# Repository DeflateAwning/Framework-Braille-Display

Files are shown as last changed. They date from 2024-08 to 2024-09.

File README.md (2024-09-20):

# Framework-Braille-Display
A braille display for the Framework 13 laptop's touchpad, hopefully

## Project Status

⚠️ This project is still a work in progress. It is not usable, yet. ⚠️

If you are interested in helping design, test, or advise on this project, please reach out!

I'm not sure how long this project will take. The goal is to have a proof of concept by 2025-06-01.

## What is this?

This is a project to create a refreshable braille display, which is installable in the location of the Framework 13 laptop's touchpad.

A braille display is a device that allows blind and visually impaired people to read text on a computer screen by converting it to braille.

Manufacturing techniques, cost, etc. TBD.

## Why?

I am not blind. I am, however, disappointed in the lack of laptop-compatible braille displays, and the lack of affordable braille displays in general. I believe that an addition to the open source Framework laptop is a great way to make computers more accessible to visually impaired people from all countries.

### Braille Standards

* ISO 17049:2013 (Accessible design — Application of braille on signage, equipment and appliances)

| Parameter | Min (mm) | Max (mm) | Nominal for Embossing (mm) |
|---|---|---|---|
| Dot Base Diameter | 1.5 | 1.6 | 1.44 |
| Dot height | 0.6 | 0.9 | 0.48 |
| Dist. between two dots in the same cell | 2.3 | 2.5 | 2.34 |
| Dist. between corresponding dots in cells (char-to-char) | 6.1 | 7.6 | 6.20 |
| Dist. between corresponding dots in cells (row-to-row) | 10.0 | 10.2 | 10.00 |

### Framework Laptop
* CAD and electrical specs for the Framework 13 laptop: https://github.com/FrameworkComputer/Framework-Laptop-13

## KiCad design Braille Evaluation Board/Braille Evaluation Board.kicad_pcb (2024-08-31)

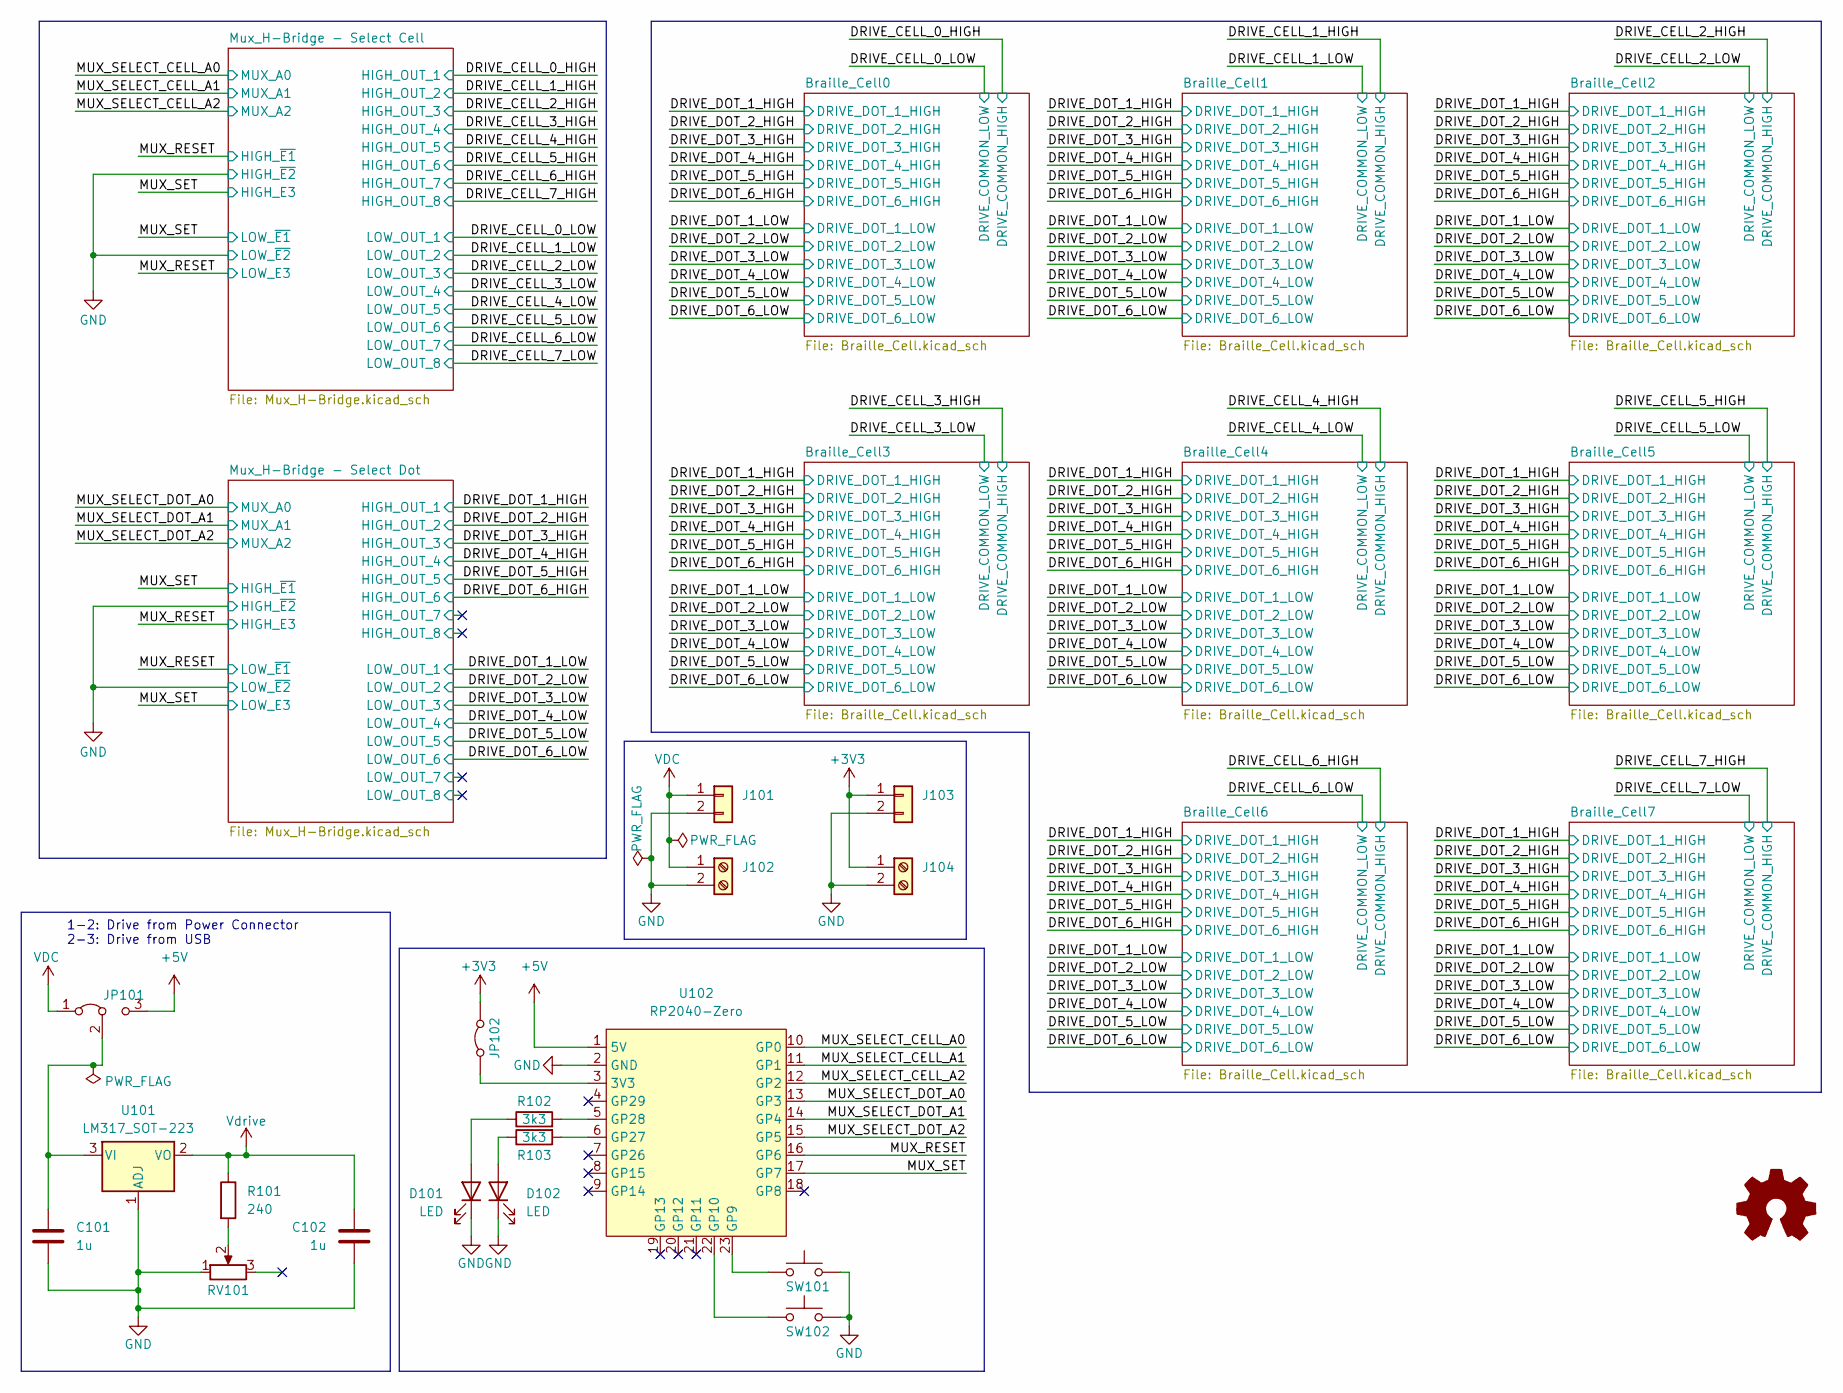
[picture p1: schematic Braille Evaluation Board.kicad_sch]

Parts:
C101, C102: 1u; C_1206_3216Metric_Pad1.33x1.80mm_HandSolder
D101, D102: LED; LED_1206_3216Metric_Pad1.42x1.75mm_HandSolder
J101, J103: Conn_01x02; PinHeader_1x02_P2.54mm_Vertical
J102, J104: Screw_Terminal_01x02; TerminalBlock_bornier-2_P5.08mm
JP101: Jumper_3_Bridged12; PinHeader_1x03_P2.54mm_Vertical
JP102: Jumper_2_Open; PinHeader_1x02_P2.54mm_Vertical
R101: 240; R_1206_3216Metric_Pad1.30x1.75mm_HandSolder
R102, R103: 3k3; R_1206_3216Metric_Pad1.30x1.75mm_HandSolder
RV101: R_Potentiometer; Potentiometer_Vishay_T73YP_Vertical
SW101, SW102: SW_Push; SW_PUSH_6mm_H5mm
U101: LM317_SOT-223; SOT-223-3_TabPin2
U102: RP2040-Zero; RP2040 Zero

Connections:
+3V3: J103.1, J104.1, JP102.2 (B); also elsewhere on the board
+5V: JP101.3 (B), U102.1 (5V)
/MUX_RESET: U102.16 (GP6); also elsewhere on the board
/MUX_SELECT_CELL_A0: U102.10 (GP0); also elsewhere on the board
/MUX_SELECT_CELL_A1: U102.11 (GP1); also elsewhere on the board
/MUX_SELECT_CELL_A2: U102.12 (GP2); also elsewhere on the board
/MUX_SELECT_DOT_A0: U102.13 (GP3); also elsewhere on the board
/MUX_SELECT_DOT_A1: U102.14 (GP4); also elsewhere on the board
/MUX_SELECT_DOT_A2: U102.15 (GP5); also elsewhere on the board
/MUX_SET: U102.17 (GP7); also elsewhere on the board
GND: C101.2, C102.2, D101.1 (K), D102.1 (K), J101.2, J102.2, J103.2, J104.2, RV101.1, SW101.2, SW102.2, U101.1 (ADJ), U102.2 (GND); also elsewhere on the board
unnamed: D101.2 (A), R102.1
unnamed: D102.2 (A), R103.1
unnamed: C101.1, JP101.2 (C), U101.3 (VI)
unnamed: JP102.1 (A), U102.3 (3V3)
unnamed: R101.2, RV101.2
unnamed: SW101.1, U102.23 (GP9)
unnamed: SW102.1, U102.22 (GP10)
unnamed: R103.2, U102.6 (GP27)
unnamed: R102.2, U102.5 (GP28)
VDC: J101.1, J102.1, JP101.1 (A)
Vdrive: C102.1, R101.1, U101.2 (VO); also elsewhere on the board

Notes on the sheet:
1-2: Drive from Power Connector 2-3: Drive from USB

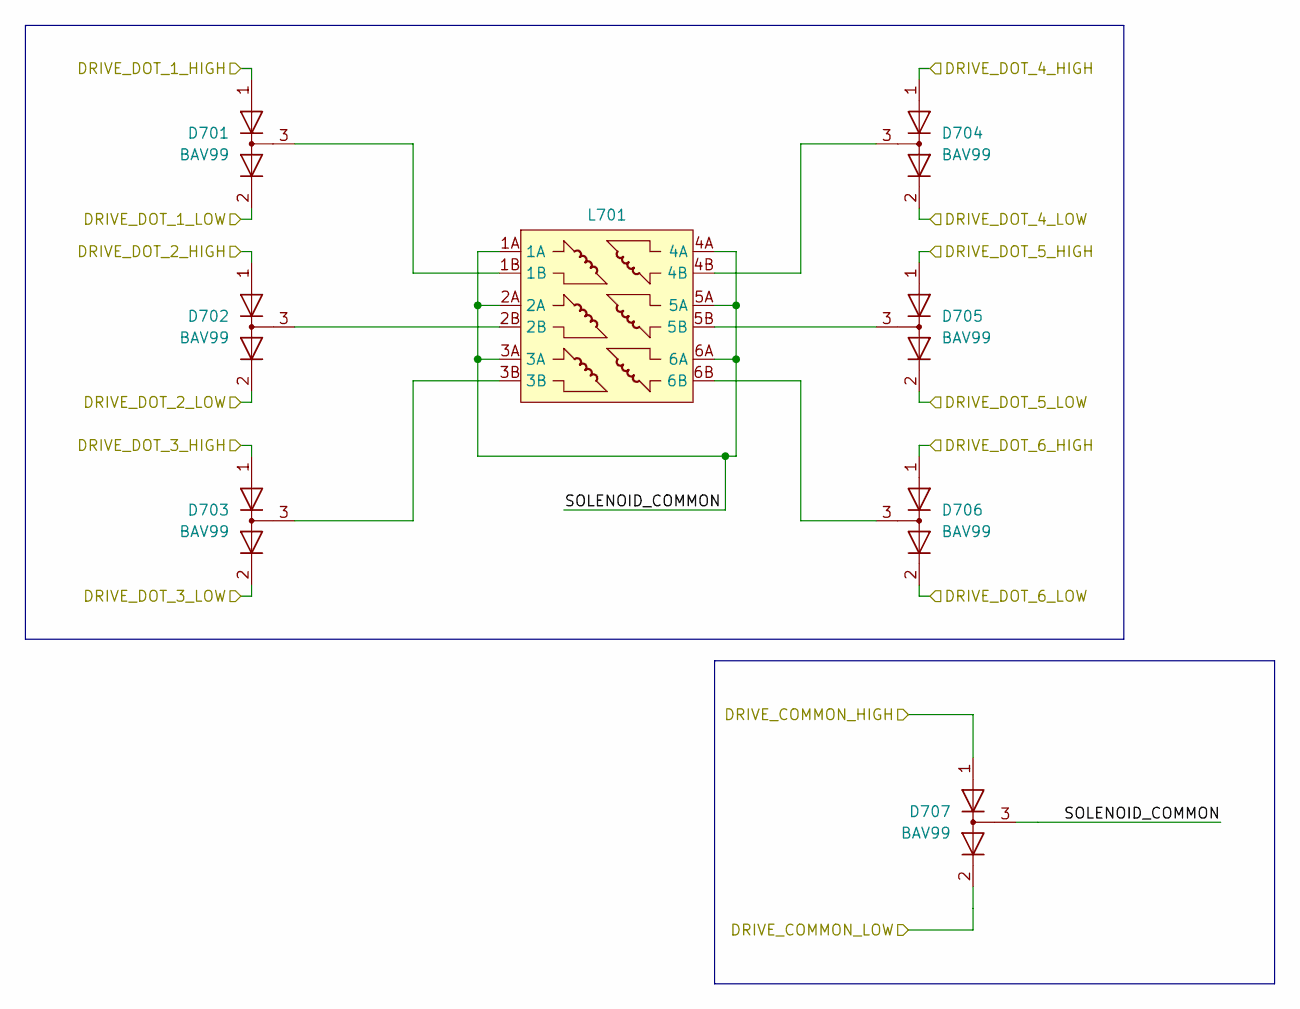
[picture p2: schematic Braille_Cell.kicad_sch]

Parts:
D701, D702, D703, D704, D705, D706, D707: BAV99; SOT-23_Handsoldering_EasyMode
L701: Solenoid_Braille_Cell

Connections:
/Braille_Cell3/SOLENOID_COMMON: D707.3 (K), L701.1A, L701.2A, L701.3A, L701.4A, L701.5A, L701.6A
/DRIVE_CELL_3_HIGH: D707.1 (K); also elsewhere on the board
/DRIVE_CELL_3_LOW: D707.2 (A); also elsewhere on the board
/DRIVE_DOT_1_HIGH: D701.1 (K); also elsewhere on the board
/DRIVE_DOT_1_LOW: D701.2 (A); also elsewhere on the board
/DRIVE_DOT_2_HIGH: D702.1 (K); also elsewhere on the board
/DRIVE_DOT_2_LOW: D702.2 (A); also elsewhere on the board
/DRIVE_DOT_3_HIGH: D703.1 (K); also elsewhere on the board
/DRIVE_DOT_3_LOW: D703.2 (A); also elsewhere on the board
/DRIVE_DOT_4_HIGH: D704.1 (K); also elsewhere on the board
/DRIVE_DOT_4_LOW: D704.2 (A); also elsewhere on the board
/DRIVE_DOT_5_HIGH: D705.1 (K); also elsewhere on the board
/DRIVE_DOT_5_LOW: D705.2 (A); also elsewhere on the board
/DRIVE_DOT_6_HIGH: D706.1 (K); also elsewhere on the board
/DRIVE_DOT_6_LOW: D706.2 (A); also elsewhere on the board
unnamed: D701.3 (K), L701.1B
unnamed: D702.3 (K), L701.2B
unnamed: D703.3 (K), L701.3B
unnamed: D704.3 (K), L701.4B
unnamed: D705.3 (K), L701.5B
unnamed: D706.3 (K), L701.6B

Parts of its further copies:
D401, D402, D403, D404, D405, D406, D407, D501, D502, D503, D504, D505, D506, D507, D601, D602, D603, D604, D605, D606, D607, D801, D802, D803, D804, D805, D806, D807, D901, D902, D903, D904, D905, D906, D907, D1001, D1002, D1003, D1004, D1005, D1006, D1007, D1101, D1102, D1103, D1104, D1105, D1106, D1107: BAV99; SOT-23_Handsoldering_EasyMode
L401, L501, L601, L801, L901, L1001, L1101: Solenoid_Braille_Cell

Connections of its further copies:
/Braille_Cell0/SOLENOID_COMMON: D407.3 (K), L401.1A, L401.2A, L401.3A, L401.4A, L401.5A, L401.6A
/Braille_Cell1/SOLENOID_COMMON: D507.3 (K), L501.1A, L501.2A, L501.3A, L501.4A, L501.5A, L501.6A
/Braille_Cell2/SOLENOID_COMMON: D607.3 (K), L601.1A, L601.2A, L601.3A, L601.4A, L601.5A, L601.6A
/Braille_Cell4/SOLENOID_COMMON: D807.3 (K), L801.1A, L801.2A, L801.3A, L801.4A, L801.5A, L801.6A
/Braille_Cell5/SOLENOID_COMMON: D907.3 (K), L901.1A, L901.2A, L901.3A, L901.4A, L901.5A, L901.6A
/Braille_Cell6/SOLENOID_COMMON: D1007.3 (K), L1001.1A, L1001.2A, L1001.3A, L1001.4A, L1001.5A, L1001.6A
/Braille_Cell7/SOLENOID_COMMON: D1107.3 (K), L1101.1A, L1101.2A, L1101.3A, L1101.4A, L1101.5A, L1101.6A
/DRIVE_CELL_0_HIGH: D407.1 (K); also elsewhere on the board
/DRIVE_CELL_0_LOW: D407.2 (A); also elsewhere on the board
/DRIVE_CELL_1_HIGH: D507.1 (K); also elsewhere on the board
/DRIVE_CELL_1_LOW: D507.2 (A); also elsewhere on the board
/DRIVE_CELL_2_HIGH: D607.1 (K); also elsewhere on the board
/DRIVE_CELL_2_LOW: D607.2 (A); also elsewhere on the board
/DRIVE_CELL_4_HIGH: D807.1 (K); also elsewhere on the board
/DRIVE_CELL_4_LOW: D807.2 (A); also elsewhere on the board
/DRIVE_CELL_5_HIGH: D907.1 (K); also elsewhere on the board
/DRIVE_CELL_5_LOW: D907.2 (A); also elsewhere on the board
/DRIVE_CELL_6_HIGH: D1007.1 (K); also elsewhere on the board
/DRIVE_CELL_6_LOW: D1007.2 (A); also elsewhere on the board
/DRIVE_CELL_7_HIGH: D1107.1 (K); also elsewhere on the board
/DRIVE_CELL_7_LOW: D1107.2 (A); also elsewhere on the board
/DRIVE_DOT_1_HIGH: D401.1 (K), D501.1 (K), D601.1 (K), D801.1 (K), D901.1 (K), D1001.1 (K), D1101.1 (K); also elsewhere on the board
/DRIVE_DOT_1_LOW: D401.2 (A), D501.2 (A), D601.2 (A), D801.2 (A), D901.2 (A), D1001.2 (A), D1101.2 (A); also elsewhere on the board
/DRIVE_DOT_2_HIGH: D402.1 (K), D502.1 (K), D602.1 (K), D802.1 (K), D902.1 (K), D1002.1 (K), D1102.1 (K); also elsewhere on the board
/DRIVE_DOT_2_LOW: D402.2 (A), D502.2 (A), D602.2 (A), D802.2 (A), D902.2 (A), D1002.2 (A), D1102.2 (A); also elsewhere on the board
/DRIVE_DOT_3_HIGH: D403.1 (K), D503.1 (K), D603.1 (K), D803.1 (K), D903.1 (K), D1003.1 (K), D1103.1 (K); also elsewhere on the board
/DRIVE_DOT_3_LOW: D403.2 (A), D503.2 (A), D603.2 (A), D803.2 (A), D903.2 (A), D1003.2 (A), D1103.2 (A); also elsewhere on the board
/DRIVE_DOT_4_HIGH: D404.1 (K), D504.1 (K), D604.1 (K), D804.1 (K), D904.1 (K), D1004.1 (K), D1104.1 (K); also elsewhere on the board
/DRIVE_DOT_4_LOW: D404.2 (A), D504.2 (A), D604.2 (A), D804.2 (A), D904.2 (A), D1004.2 (A), D1104.2 (A); also elsewhere on the board
/DRIVE_DOT_5_HIGH: D405.1 (K), D505.1 (K), D605.1 (K), D805.1 (K), D905.1 (K), D1005.1 (K), D1105.1 (K); also elsewhere on the board
/DRIVE_DOT_5_LOW: D405.2 (A), D505.2 (A), D605.2 (A), D805.2 (A), D905.2 (A), D1005.2 (A), D1105.2 (A); also elsewhere on the board
/DRIVE_DOT_6_HIGH: D406.1 (K), D506.1 (K), D606.1 (K), D806.1 (K), D906.1 (K), D1006.1 (K), D1106.1 (K); also elsewhere on the board
/DRIVE_DOT_6_LOW: D406.2 (A), D506.2 (A), D606.2 (A), D806.2 (A), D906.2 (A), D1006.2 (A), D1106.2 (A); also elsewhere on the board
unnamed: D401.3 (K), L401.1B
unnamed: D402.3 (K), L401.2B
unnamed: D403.3 (K), L401.3B
unnamed: D404.3 (K), L401.4B
unnamed: D405.3 (K), L401.5B
unnamed: D406.3 (K), L401.6B
unnamed: D501.3 (K), L501.1B
unnamed: D502.3 (K), L501.2B
unnamed: D503.3 (K), L501.3B
unnamed: D504.3 (K), L501.4B
unnamed: D505.3 (K), L501.5B
unnamed: D506.3 (K), L501.6B
unnamed: D601.3 (K), L601.1B
unnamed: D602.3 (K), L601.2B
unnamed: D603.3 (K), L601.3B
unnamed: D604.3 (K), L601.4B
unnamed: D605.3 (K), L601.5B
unnamed: D606.3 (K), L601.6B
unnamed: D801.3 (K), L801.1B
unnamed: D802.3 (K), L801.2B
unnamed: D803.3 (K), L801.3B
unnamed: D804.3 (K), L801.4B
unnamed: D805.3 (K), L801.5B
unnamed: D806.3 (K), L801.6B
unnamed: D901.3 (K), L901.1B
unnamed: D902.3 (K), L901.2B
unnamed: D903.3 (K), L901.3B
unnamed: D904.3 (K), L901.4B
unnamed: D905.3 (K), L901.5B
unnamed: D906.3 (K), L901.6B
unnamed: D1001.3 (K), L1001.1B
unnamed: D1002.3 (K), L1001.2B
unnamed: D1003.3 (K), L1001.3B
unnamed: D1004.3 (K), L1001.4B
unnamed: D1005.3 (K), L1001.5B
unnamed: D1006.3 (K), L1001.6B
unnamed: D1101.3 (K), L1101.1B
unnamed: D1102.3 (K), L1101.2B
unnamed: D1103.3 (K), L1101.3B
unnamed: D1104.3 (K), L1101.4B
unnamed: D1105.3 (K), L1101.5B
unnamed: D1106.3 (K), L1101.6B

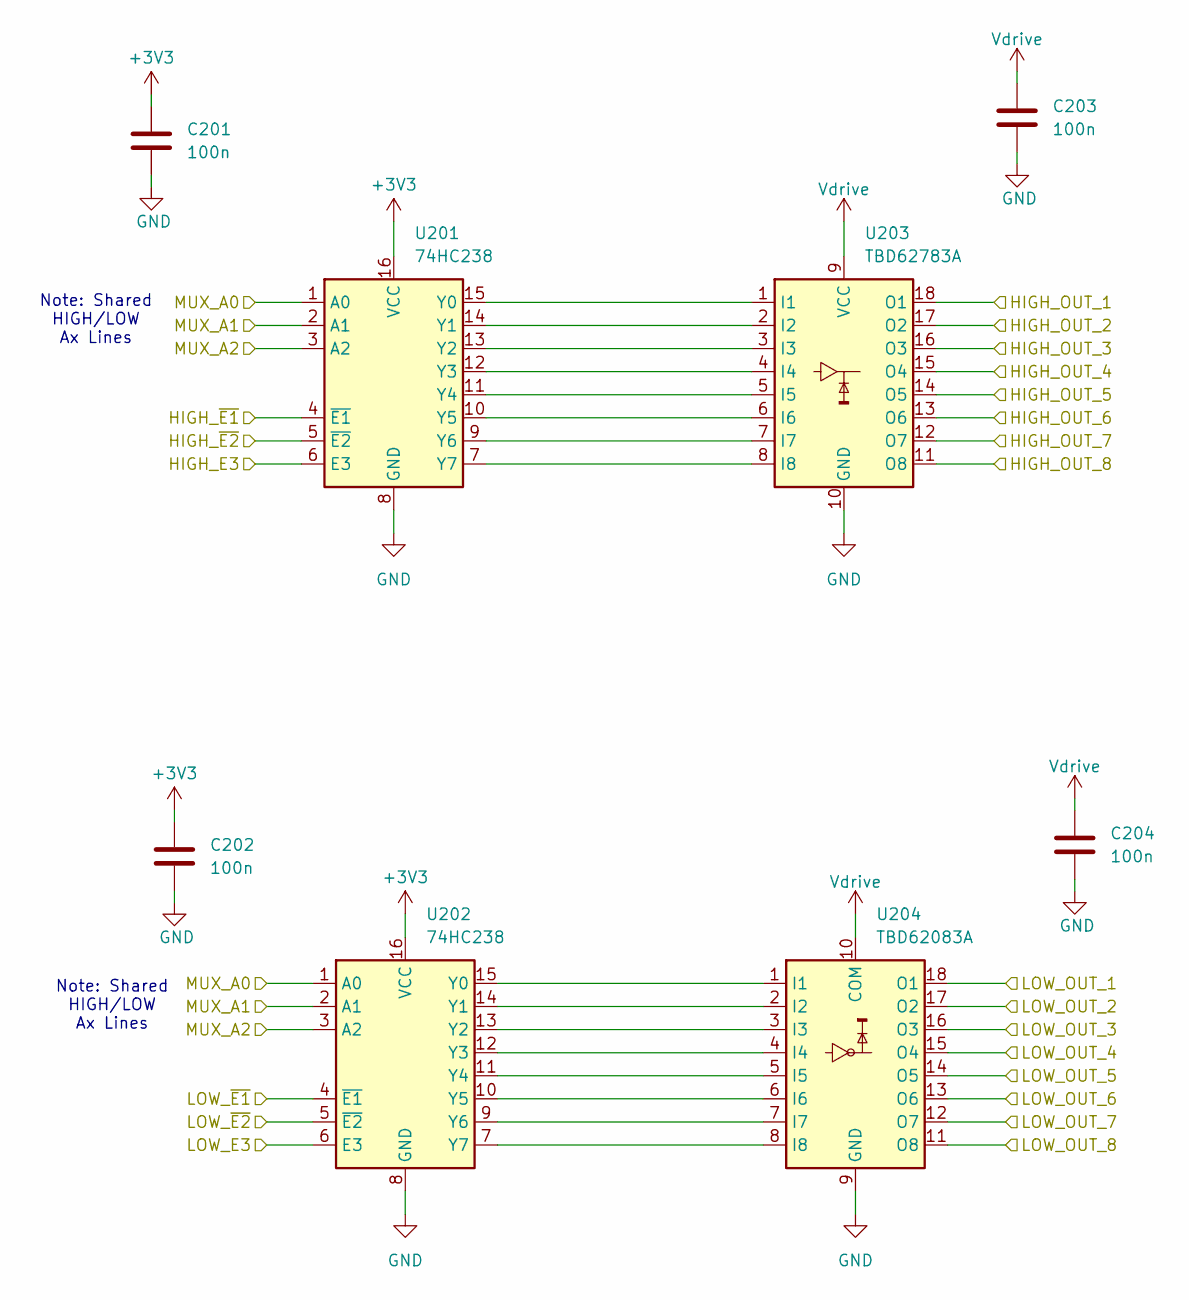
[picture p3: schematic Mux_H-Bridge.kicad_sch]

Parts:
C201, C202, C203, C204: 100n; C_1206_3216Metric_Pad1.33x1.80mm_HandSolder
U201, U202: 74HC238; SOIC-16_3.9x9.9mm_P1.27mm
U203: TBD62783A; SOIC-18W_7.5x11.6mm_P1.27mm
U204: TBD62083A; SOIC-18W_7.5x11.6mm_P1.27mm

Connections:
+3V3: C201.1, C202.1, U201.16 (VCC), U202.16 (VCC); also elsewhere on the board
/DRIVE_CELL_0_HIGH: U203.18 (O1); also elsewhere on the board
/DRIVE_CELL_0_LOW: U204.18 (O1); also elsewhere on the board
/DRIVE_CELL_1_HIGH: U203.17 (O2); also elsewhere on the board
/DRIVE_CELL_1_LOW: U204.17 (O2); also elsewhere on the board
/DRIVE_CELL_2_HIGH: U203.16 (O3); also elsewhere on the board
/DRIVE_CELL_2_LOW: U204.16 (O3); also elsewhere on the board
/DRIVE_CELL_3_HIGH: U203.15 (O4); also elsewhere on the board
/DRIVE_CELL_3_LOW: U204.15 (O4); also elsewhere on the board
/DRIVE_CELL_4_HIGH: U203.14 (O5); also elsewhere on the board
/DRIVE_CELL_4_LOW: U204.14 (O5); also elsewhere on the board
/DRIVE_CELL_5_HIGH: U203.13 (O6); also elsewhere on the board
/DRIVE_CELL_5_LOW: U204.13 (O6); also elsewhere on the board
/DRIVE_CELL_6_HIGH: U203.12 (O7); also elsewhere on the board
/DRIVE_CELL_6_LOW: U204.12 (O7); also elsewhere on the board
/DRIVE_CELL_7_HIGH: U203.11 (O8); also elsewhere on the board
/DRIVE_CELL_7_LOW: U204.11 (O8); also elsewhere on the board
/MUX_RESET: U201.4 (~E1), U202.6 (E3); also elsewhere on the board
/MUX_SELECT_CELL_A0: U201.1 (A0), U202.1 (A0); also elsewhere on the board
/MUX_SELECT_CELL_A1: U201.2 (A1), U202.2 (A1); also elsewhere on the board
/MUX_SELECT_CELL_A2: U201.3 (A2), U202.3 (A2); also elsewhere on the board
/MUX_SET: U201.6 (E3), U202.4 (~E1); also elsewhere on the board
GND: C201.2, C202.2, C203.2, C204.2, U201.5 (~E2), U201.8 (GND), U202.5 (~E2), U202.8 (GND), U203.10 (GND), U204.9 (GND); also elsewhere on the board
unnamed: U201.15 (Y0), U203.1 (I1)
unnamed: U201.14 (Y1), U203.2 (I2)
unnamed: U201.13 (Y2), U203.3 (I3)
unnamed: U201.12 (Y3), U203.4 (I4)
unnamed: U201.11 (Y4), U203.5 (I5)
unnamed: U201.10 (Y5), U203.6 (I6)
unnamed: U201.9 (Y6), U203.7 (I7)
unnamed: U201.7 (Y7), U203.8 (I8)
unnamed: U202.15 (Y0), U204.1 (I1)
unnamed: U202.14 (Y1), U204.2 (I2)
unnamed: U202.13 (Y2), U204.3 (I3)
unnamed: U202.12 (Y3), U204.4 (I4)
unnamed: U202.11 (Y4), U204.5 (I5)
unnamed: U202.10 (Y5), U204.6 (I6)
unnamed: U202.9 (Y6), U204.7 (I7)
unnamed: U202.7 (Y7), U204.8 (I8)
Vdrive: C203.1, C204.1, U203.9 (VCC), U204.10 (COM); also elsewhere on the board

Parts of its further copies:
C301, C302, C303, C304: 100n; C_1206_3216Metric_Pad1.33x1.80mm_HandSolder
U301, U302: 74HC238; SOIC-16_3.9x9.9mm_P1.27mm
U303: TBD62783A; SOIC-18W_7.5x11.6mm_P1.27mm
U304: TBD62083A; SOIC-18W_7.5x11.6mm_P1.27mm

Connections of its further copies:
+3V3: C301.1, C302.1, U301.16 (VCC), U302.16 (VCC); also elsewhere on the board
/DRIVE_DOT_1_HIGH: U303.18 (O1); also elsewhere on the board
/DRIVE_DOT_1_LOW: U304.18 (O1); also elsewhere on the board
/DRIVE_DOT_2_HIGH: U303.17 (O2); also elsewhere on the board
/DRIVE_DOT_2_LOW: U304.17 (O2); also elsewhere on the board
/DRIVE_DOT_3_HIGH: U303.16 (O3); also elsewhere on the board
/DRIVE_DOT_3_LOW: U304.16 (O3); also elsewhere on the board
/DRIVE_DOT_4_HIGH: U303.15 (O4); also elsewhere on the board
/DRIVE_DOT_4_LOW: U304.15 (O4); also elsewhere on the board
/DRIVE_DOT_5_HIGH: U303.14 (O5); also elsewhere on the board
/DRIVE_DOT_5_LOW: U304.14 (O5); also elsewhere on the board
/DRIVE_DOT_6_HIGH: U303.13 (O6); also elsewhere on the board
/DRIVE_DOT_6_LOW: U304.13 (O6); also elsewhere on the board
/MUX_RESET: U301.6 (E3), U302.4 (~E1); also elsewhere on the board
/MUX_SELECT_DOT_A0: U301.1 (A0), U302.1 (A0); also elsewhere on the board
/MUX_SELECT_DOT_A1: U301.2 (A1), U302.2 (A1); also elsewhere on the board
/MUX_SELECT_DOT_A2: U301.3 (A2), U302.3 (A2); also elsewhere on the board
/MUX_SET: U301.4 (~E1), U302.6 (E3); also elsewhere on the board
/Mux_H-Bridge - Select Dot/HIGH_OUT_7: U303.12 (O7)
/Mux_H-Bridge - Select Dot/HIGH_OUT_8: U303.11 (O8)
/Mux_H-Bridge - Select Dot/LOW_OUT_7: U304.12 (O7)
/Mux_H-Bridge - Select Dot/LOW_OUT_8: U304.11 (O8)
GND: C301.2, C302.2, C303.2, C304.2, U301.5 (~E2), U301.8 (GND), U302.5 (~E2), U302.8 (GND), U303.10 (GND), U304.9 (GND); also elsewhere on the board
unnamed: U301.15 (Y0), U303.1 (I1)
unnamed: U301.14 (Y1), U303.2 (I2)
unnamed: U301.13 (Y2), U303.3 (I3)
unnamed: U301.12 (Y3), U303.4 (I4)
unnamed: U301.11 (Y4), U303.5 (I5)
unnamed: U301.10 (Y5), U303.6 (I6)
unnamed: U301.9 (Y6), U303.7 (I7)
unnamed: U301.7 (Y7), U303.8 (I8)
unnamed: U302.15 (Y0), U304.1 (I1)
unnamed: U302.14 (Y1), U304.2 (I2)
unnamed: U302.13 (Y2), U304.3 (I3)
unnamed: U302.12 (Y3), U304.4 (I4)
unnamed: U302.11 (Y4), U304.5 (I5)
unnamed: U302.10 (Y5), U304.6 (I6)
unnamed: U302.9 (Y6), U304.7 (I7)
unnamed: U302.7 (Y7), U304.8 (I8)
Vdrive: C303.1, C304.1, U303.9 (VCC), U304.10 (COM); also elsewhere on the board

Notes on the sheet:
Note: Shared HIGH/LOW Ax Lines

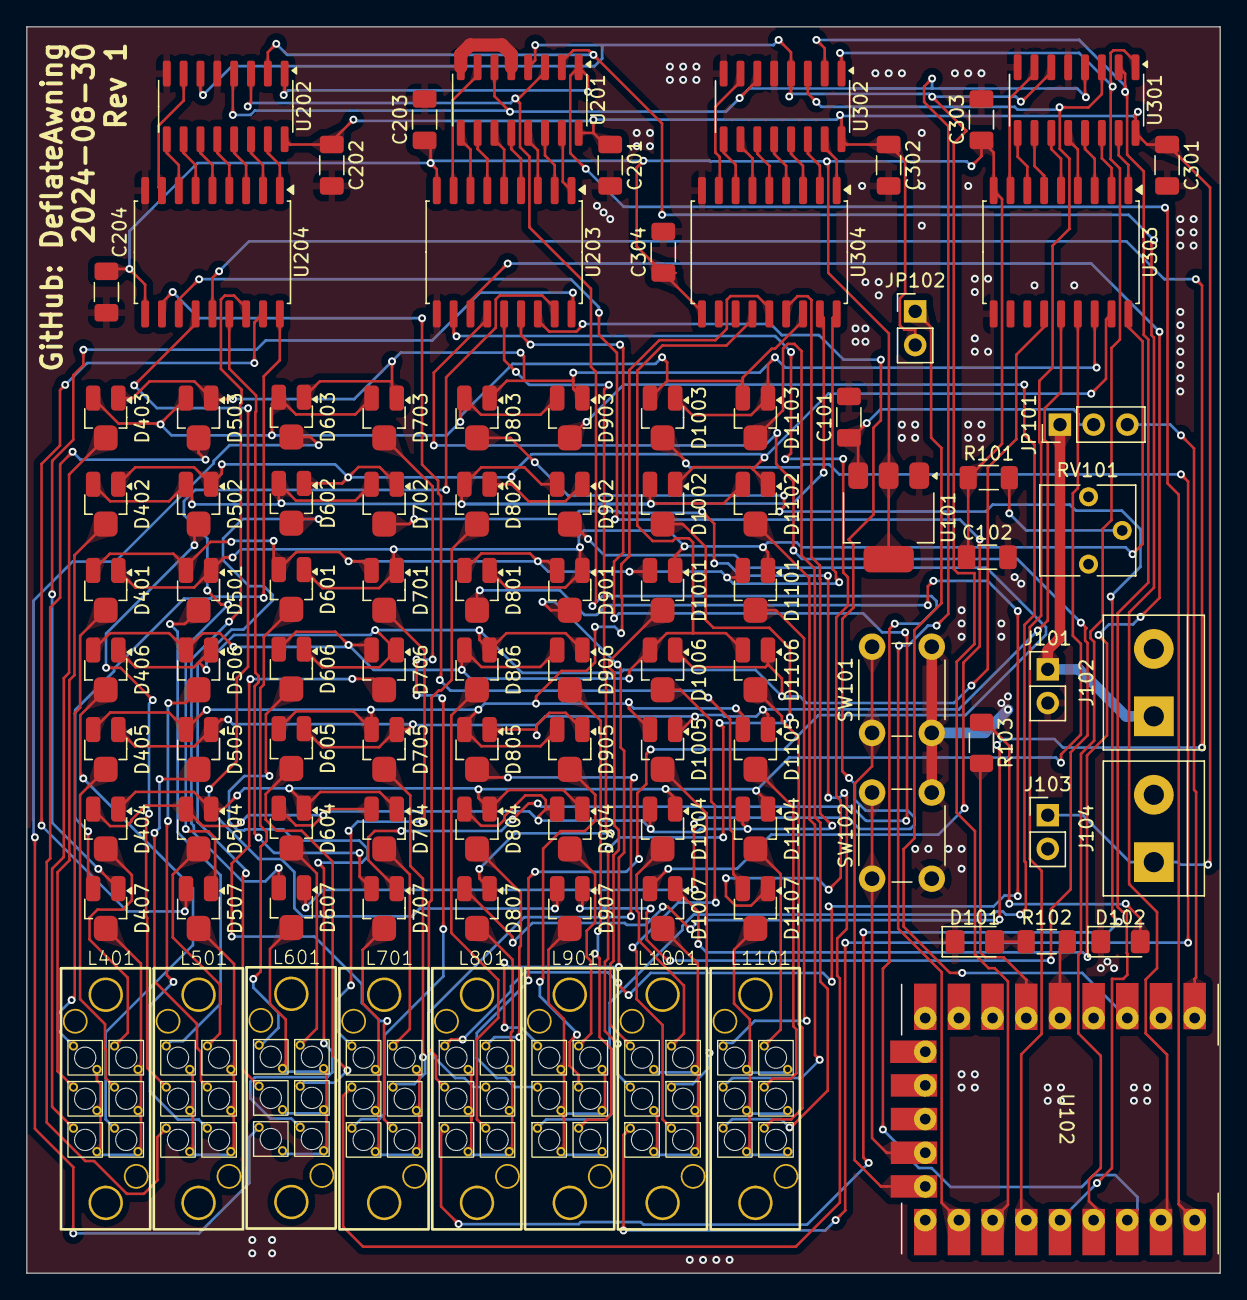
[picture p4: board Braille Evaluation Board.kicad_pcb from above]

Board: 2 copper layers, 90.0 x 94.0 mm, 98 parts (0 on the bottom side), 138 nets.

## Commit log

2024-08-31 Create PCB design
    [Braille Cell Pad Placement Calculation.ods, Braille Evaluation Board.kicad_pcb, Braille Evaluation Board.kicad_sch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]
2024-08-31 Create Rev 1
    [Braille Evaluation Board.kicad_pcb, Braille Evaluation Board.kicad_sch, Braille_Cell.kicad_sch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]
